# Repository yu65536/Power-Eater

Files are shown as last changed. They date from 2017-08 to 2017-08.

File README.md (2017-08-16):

# Power-Eater
  
This is Ni-MH battery charger for mini4wd.  
 - very low noise and low ripple  
 - dv charge / discharge  
 - cccvdv charge (i thinked new method for mini4wd charger)  
   - race charge method  
   - low internal resigtance, high voltage, many capacity  
   - low life  
 - programable charge/discharge sequence  
   - can use battery tester  
   - complex sequence like IF  

ミニ四駆用ニッケル水素充電器です。  
 - ノイズやリプルが少ない  
 - dv充電や放電ができる  
 - cccvdv充電ができる  
   - レース用途に適している  
   - dv方式に比べて、低内部抵抗、高電圧、大容量の充電が可能  
   - 寿命は短くなる  
 - 充放電シーケンスを組むことができる  
   - 簡易充放電試験機として使用可能  
   - プログラムのIF文のような分岐も可能

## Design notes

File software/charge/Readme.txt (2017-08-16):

-------- PROJECT GENERATOR --------
PROJECT NAME :	charge
PROJECT DIRECTORY :	C:\WorkSpace\charge\charge
CPU SERIES :	R8C/Tiny
CPU GROUP :	25
TOOLCHAIN NAME :	Renesas M16C Standard Toolchain
TOOLCHAIN VERSION :	6.00.00
GENERATION FILES :
    C:\WorkSpace\charge\charge\charge.c
        main program file.
    C:\WorkSpace\charge\charge\nc_define.inc
        interrupt program.
START UP FILES :
    C:\WorkSpace\charge\charge\ncrt0.a30
    C:\WorkSpace\charge\charge\sect30.inc
    C:\WorkSpace\charge\charge\sfr_r825.h
    C:\WorkSpace\charge\charge\sfr_r825.inc

DATE & TIME : 2016/03/07 0:31:16

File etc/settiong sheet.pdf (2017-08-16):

CHG 0 | | CHG 5 | | CHG A | | CHG F
current | A | current | A | current | A | current | A
delta_peak | mV | delta_peak | mV | delta_peak | mV | delta_peak | mV
peak_delay | sec | peak_delay | sec | peak_delay | sec | peak_delay | sec
stop_voltage | V | stop_voltage | V | stop_voltage | V | stop_voltage | V
mode | | mode | | mode | | mode
dec speed | | dec speed | | dec speed | | dec speed
stop current | A | stop current | A | stop current | A | stop current | A
capacity | mAh | capacity | mAh | capacity | mAh | capacity | mAh
CHG 1 | | CHG 6 | | CHG B | | CHG
current | A | current | A | current | A | current | A
delta_peak | mV | delta_peak | mV | delta_peak | mV | delta_peak | mV
peak_delay | sec | peak_delay | sec | peak_delay | sec | peak_delay | sec
stop_voltage | V | stop_voltage | V | stop_voltage | V | stop_voltage | V
mode | | mode | | mode | | mode
dec speed | | dec speed | | dec speed | | dec speed
stop current | A | stop current | A | stop current | A | stop current | A
capacity | mAh | capacity | mAh | capacity | mAh | capacity | mAh
CHG 2 | | CHG 7 | | CHG C | | CHG
current | A | current | A | current | A | current | A
delta_peak | mV | delta_peak | mV | delta_peak | mV | delta_peak | mV
peak_delay | sec | peak_delay | sec | peak_delay | sec | peak_delay | sec
stop_voltage | V | stop_voltage | V | stop_voltage | V | stop_voltage | V
mode | | mode | | mode | | mode
dec speed | | dec speed | | dec speed | | dec speed
stop current | A | stop current | A | stop current | A | stop current | A
capacity | mAh | capacity | mAh | capacity | mAh | capacity | mAh
CHG 3 | | CHG 8 | | CHG D | | CHG
current | A | current | A | current | A | current | A
delta_peak | mV | delta_peak | mV | delta_peak | mV | delta_peak | mV
peak_delay | sec | peak_delay | sec | peak_delay | sec | peak_delay | sec
stop_voltage | V | stop_voltage | V | stop_voltage | V | stop_voltage | V
mode | | mode | | mode | | mode
dec speed | | dec speed | | dec speed | | dec speed
stop current | A | stop current | A | stop current | A | stop current | A
capacity | mAh | capacity | mAh | capacity | mAh | capacity | mAh
CHG 4 | | CHG 9 | | CHG E | | CHG
current | A | current | A | current | A | current | A
delta_peak | mV | delta_peak | mV | delta_peak | mV | delta_peak | mV
peak_delay | sec | peak_delay | sec | peak_delay | sec | peak_delay | sec
stop_voltage | V | stop_voltage | V | stop_voltage | V | stop_voltage | V
mode | | mode | | mode | | mode
dec speed | | dec speed | | dec speed | | dec speed
stop current | A | stop current | A | stop current | A | stop current | A
capacity | mAh | capacity | mAh | capacity | mAh | capacity | mAh

DIS 0 | | DIS 5 | | DIS A | | DIS F
current | A | current | A | current | A | current | A
stop_voltage | V | stop_voltage | V | stop_voltage | V | stop_voltage | V
shibori | | shibori | | shibori | | shibori
dec speed | | dec speed | | dec speed | | dec speed
stop current | A | stop current | A | stop current | A | stop current | A
capacity | mAh | capacity | mAh | capacity | mAh | capacity | mAh
DIS 1 | | DIS 6 | | DIS B | | DIS
current | A | current | A | current | A | current | A
stop_voltage | V | stop_voltage | V | stop_voltage | V | stop_voltage | V
shibori | | shibori | | shibori | | shibori
dec speed | | dec speed | | dec speed | | dec speed
stop current | A | stop current | A | stop current | A | stop current | A
capacity | mAh | capacity | mAh | capacity | mAh | capacity | mAh
DIS 2 | | DIS 7 | | DIS C | | DIS
current | A | current | A | current | A | current | A
stop_voltage | V | stop_voltage | V | stop_voltage | V | stop_voltage | V
shibori | | shibori | | shibori | | shibori
dec speed | | dec speed | | dec speed | | dec speed
stop current | A | stop current | A | stop current | A | stop current | A
capacity | mAh | capacity | mAh | capacity | mAh | capacity | mAh
DIS 3 | | DIS 8 | | DIS D | | DIS
current | A | current | A | current | A | current | A
stop_voltage | V | stop_voltage | V | stop_voltage | V | stop_voltage | V
shibori | | shibori | | shibori | | shibori
dec speed | | dec speed | | dec speed | | dec speed
stop current | A | stop current | A | stop current | A | stop current | A
capacity | mAh | capacity | mAh | capacity | mAh | capacity | mAh
DIS 4 | | DIS 9 | | DIS E | | DIS
current | A | current | A | current | A | current | A
stop_voltage | V | stop_voltage | V | stop_voltage | V | stop_voltage | V
shibori | | shibori | | shibori | | shibori
dec speed | | dec speed | | dec speed | | dec speed
stop current | A | stop current | A | stop current | A | stop current | A
capacity | mAh | capacity | mAh | capacity | mAh | capacity | mAh

SEQ 0 | SEQ 1 0 | 0 1 | 1 2 | 2 3 | 3 4 | 4 5 | 5 6 | 6 7 | 7 8 | 8 9 | 9 A | A B | B C | C D | D E | E F | F
10 | 10
11 | 11
12 | 12
13 | 13
14 | 14
15 | 15
16 | 16
17 | 17
18 | 18
19 | 19
1A | 1A
1B | 1B
1C | 1C
1E | 1E
1F | 1F
20 | 20
21 | 21
22 | 22
23 | 23
24 | 24
25 | 25
26 | 26
27 | 27
28 | 28
29 | 29
2A | 2A
2B | 2B
2C | 2C
2D | 2D
2E | 2E
2F | 2F

SEQ 2 | SEQ 3 0 | 0 1 | 1 2 | 2 3 | 3 4 | 4 5 | 5 6 | 6 7 | 7 8 | 8 9 | 9 A | A B | B C | C D | D E | E F | F
10 | 10
11 | 11
12 | 12
13 | 13
14 | 14
15 | 15
16 | 16
17 | 17
18 | 18
19 | 19
1A | 1A
1B | 1B
1C | 1C
1E | 1E
1F | 1F
20 | 20
21 | 21
22 | 22
23 | 23
24 | 24
25 | 25
26 | 26
27 | 27
28 | 28
29 | 29
2A | 2A
2B | 2B
2C | 2C
2D | 2D
2E | 2E
2F | 2F

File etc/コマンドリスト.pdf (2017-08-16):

## コマンドリスト

1バイト目 | 2バイト目 | 3バイト目 | 4バイト目 | 詳細 | プログラムカウンタ | 備考
0 | 0 | - | - | - cccvΔV charge 0 | | pc = pc + 1
0 | F | - | - | - cccvΔV charge F | | pc = pc + 1
2 | 0 | - | - | - discharge 0 | | pc = pc + 1
2 | F | - | - | - discharge F | | pc = pc + 1
3 | 0 | - | - | - cnt0 = 0 | | pc = pc + 1
3 | 1 | x | - | - cnt0 = x | | pc = pc + 2
3 | 4 | x | - | - cnt0 = cnt0 + x | | pc = pc + 2
3 | 5 | x | - | - cnt0 = cnt0 - x | | pc = pc + 2
3 | 6 | x | y | - if cnt0 == x goto y | | pc = pc + 3
3 | 9 | x | y | - if cnt0 > x goto y | | pc = pc + 3
4 | 0 | - | - | - cnt1 = 0 | | pc = pc + 1
4 | 1 | x | - | - cnt1 = x | | pc = pc + 2
4 | 4 | x | - | - cnt1 = cnt1 + x | | pc = pc + 2
4 | 5 | x | - | - cnt1 = cnt1 - x | | pc = pc + 2
4 | 6 | x | y | - if cnt1 == x goto y | | pc = pc + 3
4 | 9 | x | y | - if cnt1 > x goto y | | pc = pc + 3
5 | 0 | - | - | - cnt2 = 0 | | pc = pc + 1
5 | 1 | x | - | - cnt2 = x | | pc = pc + 2
5 | 4 | x | - | - cnt2 = cnt2 + x | | pc = pc + 2
5 | 5 | x | - | - cnt2 = cnt2 - x | | pc = pc + 2
5 | 6 | x | y | - if cnt2 == x goto y | | pc = pc + 3
5 | 9 | x | y | - if cnt2 > x goto y | | pc = pc + 3
6 | 0 | - | - | - cnt3 = 0 | | pc = pc + 1
6 | 1 | x | - | - cnt3 = x | | pc = pc + 2
6 | 4 | x | - | - cnt3 = cnt3 + x | | pc = pc + 2
6 | 5 | x | - | - cnt3 = cnt3 - x | | pc = pc + 2
6 | 6 | x | y | - if cnt3 == x goto y | | pc = pc + 3
6 | 9 | x | y | - if cnt3 > x goto y | | pc = pc + 3
7 | 0 | x | y | - if (end_flag) and x != 0 goto y | | pc = pc + 3 | 終了条件で分岐　※
8 | 0 | x | y | z if end_voltage == (x*256+y)/1000 then goto z | | pc = pc + 4 | 終了時の電圧で分岐
8 | 3 | x | y | z if end_voltage > (x*256+y)/1000 then goto z | | pc = pc + 4 | 終了時の電圧で分岐
8 | 6 | x | y | z if end_current == (x*256+y)/100 then goto z | | pc = pc + 4 | 終了時の電流で分岐
8 | 9 | x | y | z if end_current > (x*256+y)/100 then goto z | | pc = pc + 4 | 終了時の電流で分岐
8 | C | x | y | z if end_capacity == x*256+y then goto z | | pc = pc + 4 | 終了時の容量で分岐
8 | F | x | y | z if end_capacity > x*256+y then goto z | | pc = pc + 4 | 終了時の容量で分岐
A | 0 | x | - | - wait x sec | | pc = pc + 2
A | 1 | x | - | - wait x min | | pc = pc + 2
A | 2 | - | - | - | 容量累積モード ON | pc = pc + 1 | 初期値が不明のため、 累積モードON時は 必ず容量リセットを実行する。
A | 3 | - | - | - | 容量累積モード OFF | pc = pc + 1
A | 4 | - | - | - 容量累積モード 容量リセット | | pc = pc + 1
B | 0 | x | - | - goto x | | pc = pc + 2
C | 0 | - | - | - end | | exit
F | F | - | - | - end | | exit

※ end_flag

各充放電モードの終了に終了の原因となった条件のフラグが立ち、フラグによってシーケンスが分岐する。

各モードのフラグは下記の通り。

CCCVΔV charge | discharge

8bitのフラグを16進数に変換して入力する。
11000010なら入力する値はC2となる。

上記の場合、0, 1, 6bit目のどれかのフラグが立てば分岐する。

0：cancel | 0：cancel
1：delta voltage | 1：voltage
2：voltage | 2：current
3：current | 3：capacity
4：capacity | 4：
5： | 5：
6： | 6：
7： | 7：

# コマンドリスト

フラグ | end_flag

## CCCVΔV charge 0 cancel 1 dlta peak 2 volt 3 current 4 capacity

5
6
7

## discharge 0 cancel 1 volt 2 current 3 capacity

4
5
6
7

### 0が最上位ビット 16進数に直して入力する 11000010なら入力する値はC2となる 0, 1, 6のどれかが成立すれば分岐する

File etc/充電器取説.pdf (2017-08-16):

## 充電器 取扱説明書

【注意】
本充電器は趣味で作成した個人製作の充電器であるため、十分な数量、時間の評価を行え ていません。
使用の際には、火災や感電に十分にご注意ください。
問題が発生した際も当方は一切の責任を負わないことをご了承ください。
ミニ四駆 フラットレース向けに設計しているため、それ以外の用途では十分な性能を発揮で きない可能性があります。

【概要】
入力：DC7.4V（※1） / 5A（充電電流＋1A）
出力：ニッケル水素電池 2 セル / 4A（※2）
※1：一般的な充電器で使用している DC12V 電源では破損の恐れがあります。 DC/DC コンバータ等を使用して DC7.4V で使用してください。 ※2：設定は 7A まで可能。
フラットレースでの追い充電時の緊急用に設定できるようにしています。 7A での充放電は動作確認をしていません。
充電機能：ΔV 充電、CCCVΔV 充電、ピークディレイ、電圧カット、容量カット 放電機能：CC 放電、絞り放電、電圧カット、容量カット その他：シーケンスモード、PC モニタ機能

【特徴】
本充電器の特徴として以下の三点が挙げられる。
- 高精度な電流制御
ニッケル水素電池の充電では mV 単位で正確に電圧を検出する必要があるため、高 精度な電流制御が必要とされる。
一般的な充電器では電流制御にパルス幅変調方式（以下 PWM 方式）が使用されてい る。PWM 方式では制御素子の ON/OFF に合わせてリプル電流と呼ばれる脈流が発生し、 精度悪化の要因となっている。
本充電器ではパルス振幅変調方式（以下 PAM 方式）を採用することでリプル電流を抑 制し、より高精度な充電を行えるようにした。
- CCCVΔV 充電
充電時の電池温度を抑えることは電池寿命の増大や内部抵抗管理の簡便性に繋が るため、充電器の重要な性能の一つである。
一般的な充電器で使用される ΔV 方式の充電器では発熱による内部抵抗の変化を検 出するため、原理上、充電終了時の電池温度を発熱を抑えることは困難である。 本充電器ではニッケル水素電池向けに新たな充電方式を開発した。CCCV 方式をベー スに ΔV の検出も行うため、安全かつ低温で充電を行うことができる。

- シーケンスモード
各人の用途、趣向に合致した充電を行うためには、より多様な充電設定を行える必要 がある。
本充電器では複数の充電設定、放電設定を組み合わせたシーケンスを設定可能な モードを備える。このシーケンスモードを利用することでサイクル充電や多段階の充放電 も行うことが可能である。
また、分岐命令やカウンタも用意されており、従来の充電器では不可能である複雑な 充放電設定を行うことができる。

【接続】
下図を参考に電池ボックス、電源を接続してください。

【基本操作】
上ボタン：項目/値を変更
下ボタン：項目/値を変更
右ボタン：決定/充電時の電流変更
左ボタン：キャンセル

充電器

+ IN
- IN

+ OUT
+ OUT-S
- OUT
- OUT-S

電源

電池ボックス

※

※ 電池ボックス＋から二本、－から二本接続する。

+

+

【PC モニタ機能】
シリアルケーブル（ストレート）で PC と接続することで充放電状況を PC からモニタすることがで きます。
下記の設定は参考にターミナルソフトを設定してください。

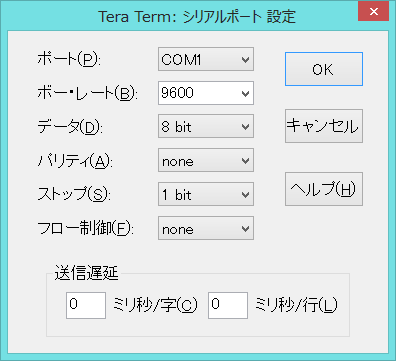
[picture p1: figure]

【フラットレースにおける充電】
フラットレースでは基礎充電、追い充電と呼ばれる充電を行います。基礎充電は電池を満充 電にするために行い、追い充電はレース直前に内部抵抗を低下させ電池出力を上げるために行 います。
追い充電での精度を上げるために、基礎充電では電池温度を上昇させずに満充電まで充電 することが重要です。
電池温度が高い状態では電池内部で自己放電と呼ばれる現象が発生し、電池の残容量は減 少していきます。どの程度放電したかはわからないため、後の追い充電にも誤差が発生します。 一般的に使用される ΔV 方式の充電器では発熱による電圧の変化を検出するため、電池温 度の低い状態では正確な ΔV の検出ができません。また ΔV はあくまでも満充電付近での発熱 を検出するだけであり、正確な満充電に至るには更に充電を行う必要があります。もちろん電池 は更に発熱します。

【CCCVΔV 充電】
前項で示した充電を行うために CCCV 充電を行う必要があります。
CCCV 充電では電池電圧が設定電圧に到達すると充電電流を低下させ、設定電圧を保持しな がら充電を行います。つまり満充電が近づくにつれ電流が低下するため、電池の発熱を最低限 に抑えることが可能です。
しかし設定電圧を ΔV 発生時の電池電圧以上に設定してしまった場合、初期電流のまま充電 を継続することとなり電池は過充電に陥ってしまいます。
本充電器では CCCV 充電と ΔV 検出を組み合わせた CCCVΔV 充電が可能です。CCCVΔV 充電 では設定電圧を誤った場合でも ΔV を検出し安全に充電を停止します。

【充電手順】
1. 充電を開始するには『CCCVΔV CHARGE』を選択してください。
2. 充電設定を選択してください。16 個の充電設定を保存出来ます。
3. 充電設定を変更します。
- CURRENT：充電電流を設定します。
- DELTA PEAK：ΔV を設定します。2 セル分の値を設定します。 （ex.6mV 設定：1 セルあたり 3mV）
- PEAK DELAY：設定した期間 ΔV の検出を行いません。
- STOP VOLT：CCCVΔV モードでは電池電圧を設定します。
CC+OVP モードでは過電圧保護閾値を設定します。
2 セル分の値を設定します。
- | CVMODE：『CV->TRICKLE』 | CCCVΔV 方式で充電後、トリクル充電を行います。
| 『CV->STOP』 | CCCVΔV 方式で充電後、停止します
| 『CC+OVP』 | ΔV 方式でします。
- STOP CUR：CCCVΔV 充電を終了する電流を設定します。『CVMODE』で『CV->TRICKLE』 を選択した場合、充電終了後に『STOP CUR』設定値でトリクル充電を行います。
- DEC SPEED：電流の減少速度を調整します。CCCVΔV で電流の減少が間に合わなけ れば増やしてください。
- STOP CAP：充電を終了する容量を設定します。
- SAVE：設定データを保存します。
4. 『START』を選択し充電を開始します。

【充電画面】
充電画面の詳細は下図の通りです。

充電中は右ボタンで電流の変更を行うことができます。
充電中は左ボタンで充電を中止することができます。

3.1234V 0123mAh
0.00A 0.00A
電池電圧 | 充電容量
設定電流 | 電流モニタ

【放電手順】
1. 放電を開始するには『DISCHARGE』を選択してください。
2. 放電設定を選択してください。16 個の放電設定を保存出来ます。
3. 放電設定を変更します。
- CURRENT：放電電流を設定します。
- STOP VOLT：終了電圧を設定します。2 セル分の値を設定します。
- SHIBORI：絞り放電の有無を設定します。
電池電圧が『STOP VOLT』に到達すると電流を減少させ放電を継続します。
- DEC SPEED：電流の減少速度を調整します。絞り放電で電流の減少が間に合わなけれ ば増やしてください。
- STOP CUR：絞り放電使用時に放電を終了する電流を設定します。
- STOP CAP：放電を終了する容量を設定します。
- SAVE：設定データを保存します。
4. 『START』を選択し放電を開始します。

放電中は左ボタンで放電を中止することができます。

【放電画面】
放電画面の詳細は下図の通りです。

放電中は左ボタンで放電を中止することができます。

3.1234V 0123mAh
0.00A 0.00A
電池電圧 | 放電容量
設定電流 | 電流モニタ

【シーケンス実行手順】
1. シーケンスを開始するには『SEQUENCE』を選択してください。
2. シーケンスを選択してください。4 個のシーケンスを保存出来ます。
3. シーケンスを変更します。
- 0～FF 行までの各行に添付のコマンドリストに従ってコマンドを入力します。
4. 『START』を選択しシーケンスを開始します。

【コマンドリストの見方】
- ①に記載された数字（16 進数）がコマンドになります。
- コマンド以外に値を必要とする場合があり②が『-』以外の場合は次の行に値を入力しま す。
- シーケンスモードでは内部変数 PC に示す行のコマンドを実行します。（PC 初期値は 0）
- コマンドの実行内容は③に記載されています。
- コマンド実行後は④で指示された値に PC を書き換え次のコマンドを実行します。 ただし②で『goto x』と記載されている場合は x で指定された値を PC に書き込みます。
1 バイト目 | 2 バイト目 | … | 詳細 | プログラムカウンタ
20 | - | | discharge 0 | PC = PC + 1
31 | x | | cnt0 = x | PC = PC + 2

【シーケンス例１】
内容：サイクル充電を 3 回行う
行番号 | 設定値 | 備考
0 | 0 | 充電設定 0 を実行
1 | 20 | 放電設定 0 を実行
2 | 0 | 充電設定 0 を実行
3 | 20 | 放電設定 0 を実行
4 | 0 | 充電設定 0 を実行
5 | 20 | 放電設定 0 を実行
6 | C0 | シーケンスを終了

SEQ0-00 SETTING
00
設定番号 | 行番号

設定値

① | ② | ③ | ④

【シーケンス例 2】
内容：サイクル充電を 100 回行う
行番号 | 設定値 | 備考
0 | 31 | cnt0 に 100 を代入
1 | 64 | 100 (16 進数)
2 | 1 | 充電設定 1 を実行
3 | A0 | 10 秒待機
4 | A | 値：10
5 | 21 | 放電設定 1 を実行
6 | 35 | cnt0 から 1 を引く
7 | 1 | 値：1
8 | A1 | 1 分待機
9 | 1 | 値：1
A | 36 | cnt0 が 0 なら F 行目に移動
B | 0 | 値：0
C | F | F 行目
D | B0 | 2 行目に移動
E | 2 | 2 行目
F | C0 | シーケンスを終了

【シーケンス例 3】
内容：2 段階充電
行番号 | 設定値 | 備考
0 | A2 | 容量累積表示モード　ON
1 | A4 | 容量を初期化
2 | 0 | 充電設定 0 を実行
3 | 70 | キャンセルされたら 7 行目に移動
4 | 80 | キャンセルフラグ
5 | 7 | 7 行目
6 | 1 | 充電設定 1 を実行
7 | A3 | 容量累積表示モード　OFF
8 | C0 | シーケンスを終了

【シーケンス例 4】
内容：電池電圧が 3.2V になるまで充放電を繰り返す（電池起こし）
行番号 | 設定値 | 備考
0 | 0 | 充電設定 0 を実行
1 | 20 | 放電設定 0 を実行（0.1A, 1mAh） （電池電圧の確認）
2 | 83 | 電池電圧が 3.2V より大きい場合 xx 行 目に移動
3 | 0B | 値：3.000V
4 | B8
5 | 9 | 9 行目
6 | 21 | 放電設定 1 を実行
7 | B0 | 0 行目に移動
8 | 0 | 0 行目
9 | 21 | 放電設定 1 を実行
A | C0 | シーケンスを終了

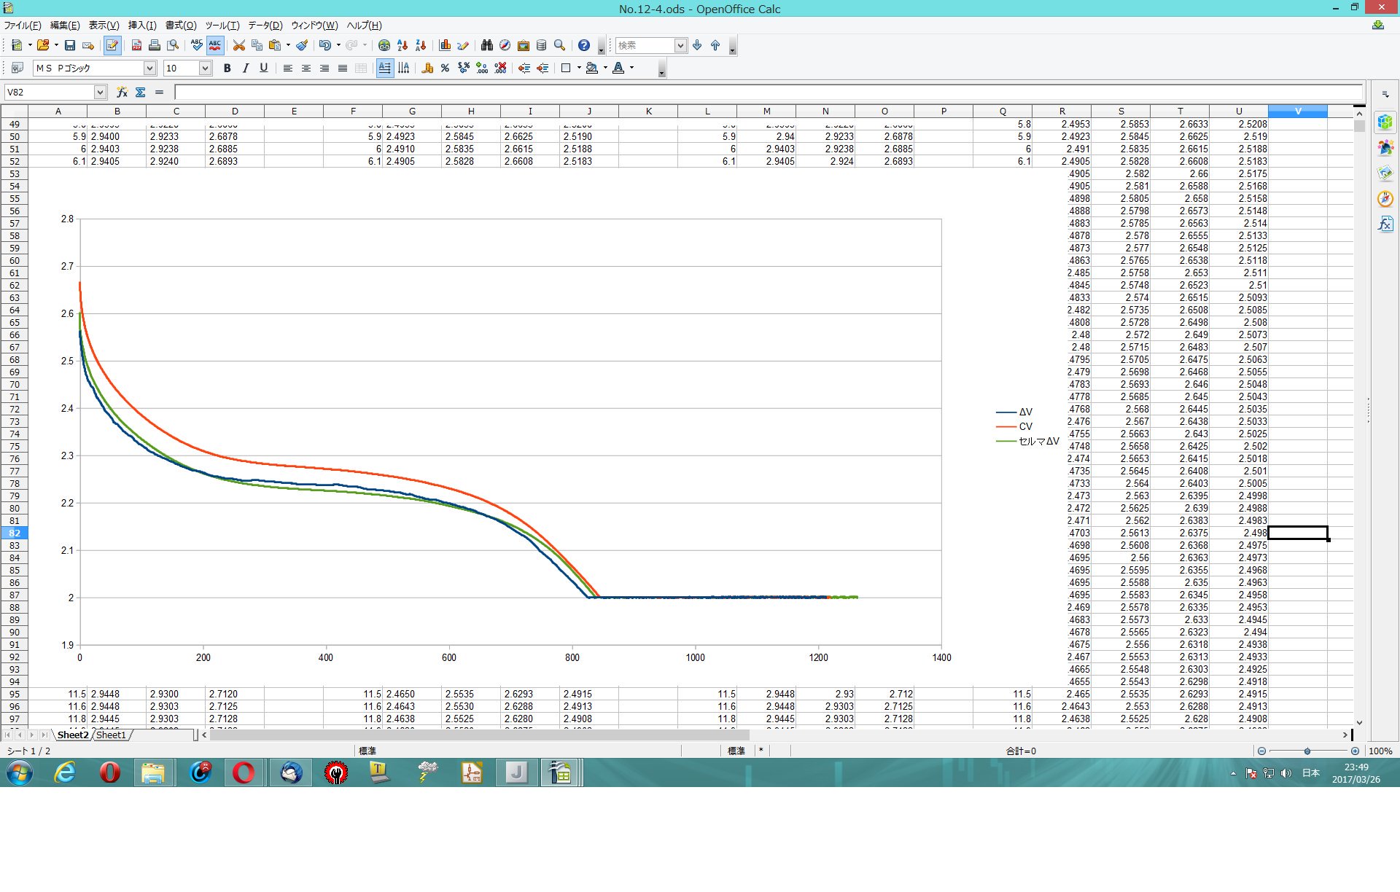
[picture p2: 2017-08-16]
etc/dv-vs-cccv.jpg

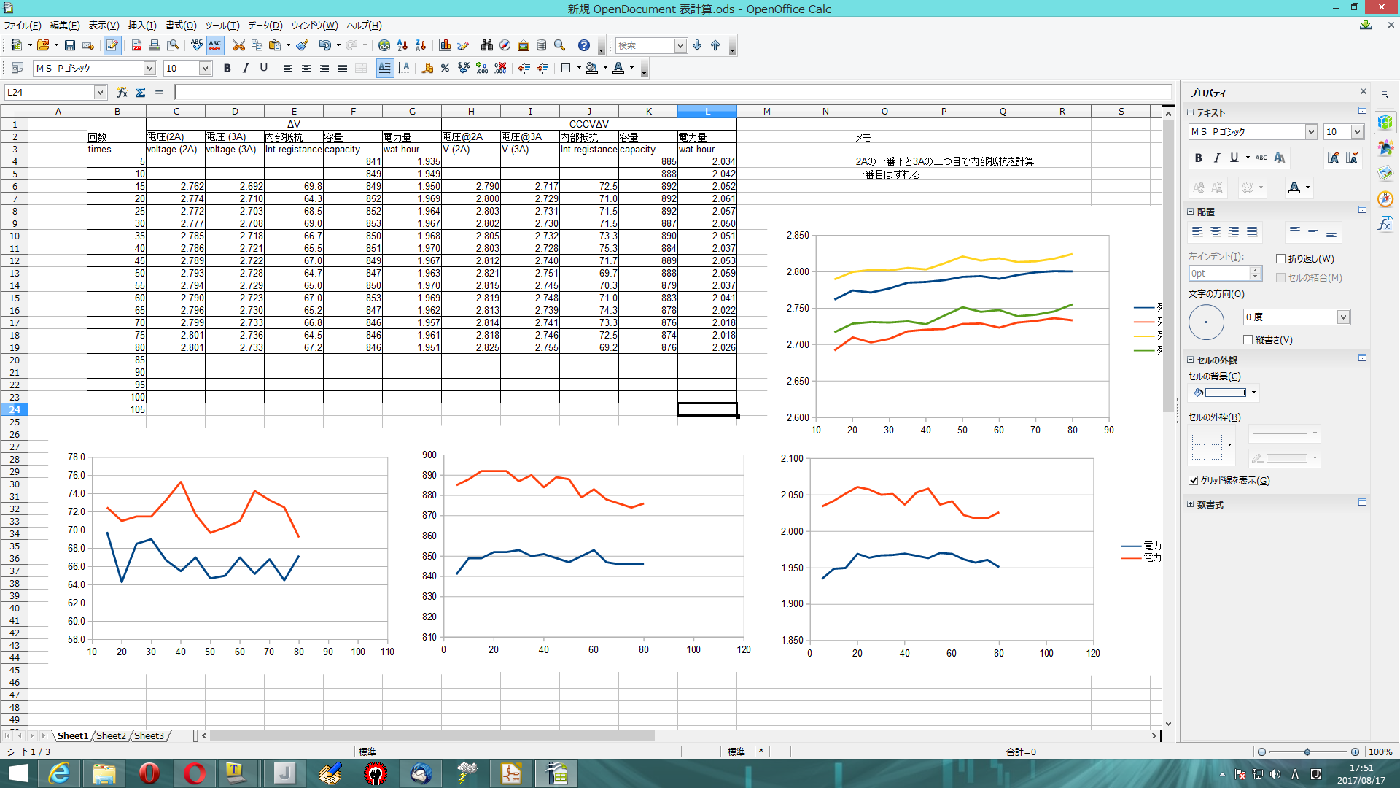
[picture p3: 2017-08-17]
etc/bat life.png

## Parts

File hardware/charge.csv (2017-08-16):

Reference | Value | Footprint | Datasheet
R13 | 0 | Resistors_SMD:R_0603
R17 | 0 | Resistors_SMD:R_0603
R3 | 1 | Resistors_SMD:R_2512
R38 | 1 | Resistors_SMD:R_2512
R39 | 1 | Resistors_SMD:R_2512
R40 | 1 | Resistors_SMD:R_2512
R41 | 1 | Resistors_SMD:R_2512
R42 | 1 | Resistors_SMD:R_2512
R43 | 1 | Resistors_SMD:R_2512
R44 | 1 | Resistors_SMD:R_2512
R45 | 1 | Resistors_SMD:R_2512
R46 | 1 | Resistors_SMD:R_2512
R47 | 1 | Resistors_SMD:R_2512
R48 | 1 | Resistors_SMD:R_2512
R49 | 1 | Resistors_SMD:R_2512
R50 | 1 | Resistors_SMD:R_2512
R51 | 1 | Resistors_SMD:R_2512
R7 | 1 | Resistors_SMD:R_2512
R14 | 100 | Resistors_SMD:R_0603
R16 | 100 | Resistors_SMD:R_0603
R20 | 100 | Resistors_SMD:R_0603
R21 | 100 | Resistors_SMD:R_0603
R27 | 100 | Resistors_SMD:R_0603
R28 | 100 | Resistors_SMD:R_0603
R29 | 100 | Resistors_SMD:R_0603
R30 | 100 | Resistors_SMD:R_0603
R15 | 470 | Resistors_SMD:R_0603
R35 | 470 | Resistors_SMD:R_0603
C36 | 0.01u | Capacitors_SMD:C_0603
C37 | 0.01u | Capacitors_SMD:C_0603
C10 | 0.1u | Capacitors_SMD:C_0603
C11 | 0.1u | Capacitors_SMD:C_0603
C12 | 0.1u | Capacitors_SMD:C_0603
C13 | 0.1u | Capacitors_SMD:C_0603
C14 | 0.1u | Capacitors_SMD:C_0603
C15 | 0.1u | Capacitors_SMD:C_0603
C17 | 0.1u | Capacitors_SMD:C_0603
C18 | 0.1u | Capacitors_SMD:C_0603
C2 | 0.1u | Capacitors_SMD:C_0603
C20 | 0.1u | Capacitors_SMD:C_0603
C23 | 0.1u | Capacitors_SMD:C_0603
C24 | 0.1u | Capacitors_SMD:C_0603
C31 | 0.1u | Capacitors_SMD:C_0603
C32 | 0.1u | Capacitors_SMD:C_0603
C33 | 0.1u | Capacitors_SMD:C_0603
C34 | 0.1u | Capacitors_SMD:C_0603
C35 | 0.1u | Capacitors_SMD:C_0603
C4 | 0.1u | Capacitors_SMD:C_0603
C5 | 0.1u | Capacitors_SMD:C_0603
C7 | 0.1u | Capacitors_SMD:C_0603
C8 | 0.1u | Capacitors_SMD:C_0603
C9 | 0.1u | Capacitors_SMD:C_0603
R11 | 10k | Resistors_SMD:R_0603
R12 | 10k | Resistors_SMD:R_0603
R19 | 10k | Resistors_SMD:R_0603
R23 | 10k | Resistors_SMD:R_0603
R24 | 10k | Resistors_SMD:R_0603
R25 | 10k | Resistors_SMD:R_0603
R26 | 10k | Resistors_SMD:R_0603
R31 | 10k | Resistors_SMD:R_0603
R32 | 10k | Resistors_SMD:R_0603
R36 | 10k | Resistors_SMD:R_0603
R37 | 10k | Resistors_SMD:R_0603
C28 | 18p | Capacitors_SMD:C_0603
C29 | 18p | Capacitors_SMD:C_0603
R10 | 1k | Resistors_SMD:R_0603
R4 | 1k | Resistors_SMD:R_0603
C19 | 1u | Capacitors_SMD:C_0805
C21 | 1u | Capacitors_SMD:C_0805
C22 | 1u | Capacitors_SMD:C_0805
C25 | 1u | Capacitors_SMD:C_0805
C30 | 1u | Capacitors_SMD:C_0805
R18 | 20k | Resistors_SMD:R_0603
R22 | 20k | Resistors_SMD:R_0603
R5 | 20k | Resistors_SMD:R_0603
R6 | 20k | Resistors_SMD:R_0603
R8 | 20k | Resistors_SMD:R_0603
R9 | 20k | Resistors_SMD:R_0603
C26 | 22p | Capacitors_SMD:C_0603
C27 | 22p | Capacitors_SMD:C_0603
Q1 | 2SD2390 | TO_SOT_Packages_THT:TO-247_PadsOnly_Neutral123
Q2 | 2SD2390 | TO_SOT_Packages_THT:TO-247_PadsOnly_Neutral123
R33 | 4.7k | Resistors_SMD:R_0603
R34 | 4.7k | Resistors_SMD:R_0603
C1 | 470u | Capacitors_ThroughHole:C_Radial_D8_L11.5_P3.5
C16 | 47u | Capacitors_ThroughHole:C_Rect_L7_W4.5_P5
C3 | 47u | Capacitors_ThroughHole:C_Rect_L7_W4.5_P5
C38 | 47u | Capacitors_ThroughHole:C_Rect_L7_W4.5_P5
C6 | 47u | Capacitors_ThroughHole:C_Radial_D5_L11_P2.5
U10 | ADM3202ARN | IC:ADM3202ARN
DS1 | AQM1602A | charge:AQM1602A
P1 | BH-6-15 | charge:BH-6-15
P10 | BH-6-15 | charge:pad-3-3
P2 | BH-6-15 | charge:BH-6-15
P3 | BH-6-15 | charge:BH-6-15
P4 | BH-6-15 | charge:BH-6-15
P5 | BH-6-15 | charge:BH-6-15
P6 | BH-6-15 | charge:BH-6-15
P7 | BH-6-15 | charge:pad-3-3
P8 | BH-6-15 | charge:pad-3-3
P9 | CONN_01X09 | Connect:DB9MD
X2 | FA-238 20MHz | Crystals:crystal_FA238-TSX3225
X1 | FC-255 32.768kHz | charge:FC-255
JP1 | JUMPER | Pin_Headers:Pin_Header_Straight_1x02
JP2 | JUMPER | Pin_Headers:Pin_Header_Straight_1x02
D10 | LED | LEDs:LED_0603
D3 | LED | LEDs:LED_0603
U2 | LM2940 | REG:LM2940CT-5.0
U8 | M51957BFP | IC:M51957B
U6 | MCP3425A0T-E/CH | TO_SOT_Packages_SMD:SOT-23-6
U7 | MCP4922-E/P | IC:MCP4922-E_P
U1 | NJM2119 | IC:NJM2119D
U3 | NJM2119 | IC:NJM2119D
U4 | NJM2119 | IC:NJM2119D
U5 | NJM2825 | TO_SOT_Packages_SMD:SOT-23-5
U9 | R5F21256SNFP | MCU_Renesas:R5F21256SNFP
D2 | RB751S-40 | Diodes_SMD:SOD-523
D4 | RB751S-40 | Diodes_SMD:SOD-523
D5 | RB751S-40 | Diodes_SMD:SOD-523
D6 | RB751S-40 | Diodes_SMD:SOD-523
D7 | RB751S-40 | Diodes_SMD:SOD-523
D8 | RB751S-40 | Diodes_SMD:SOD-523
D9 | RB751S-40 | Diodes_SMD:SOD-523
D1 | SBM1045VSS | D:SBM1045VSS
SW1 | SW_PUSH | Buttons_Switches_ThroughHole:SW_PUSH_6mm
SW2 | SW_PUSH | Buttons_Switches_ThroughHole:SW_PUSH_6mm
SW3 | SW_PUSH | Buttons_Switches_ThroughHole:SW_PUSH_6mm
SW4 | SW_PUSH | Buttons_Switches_ThroughHole:SW_PUSH_6mm

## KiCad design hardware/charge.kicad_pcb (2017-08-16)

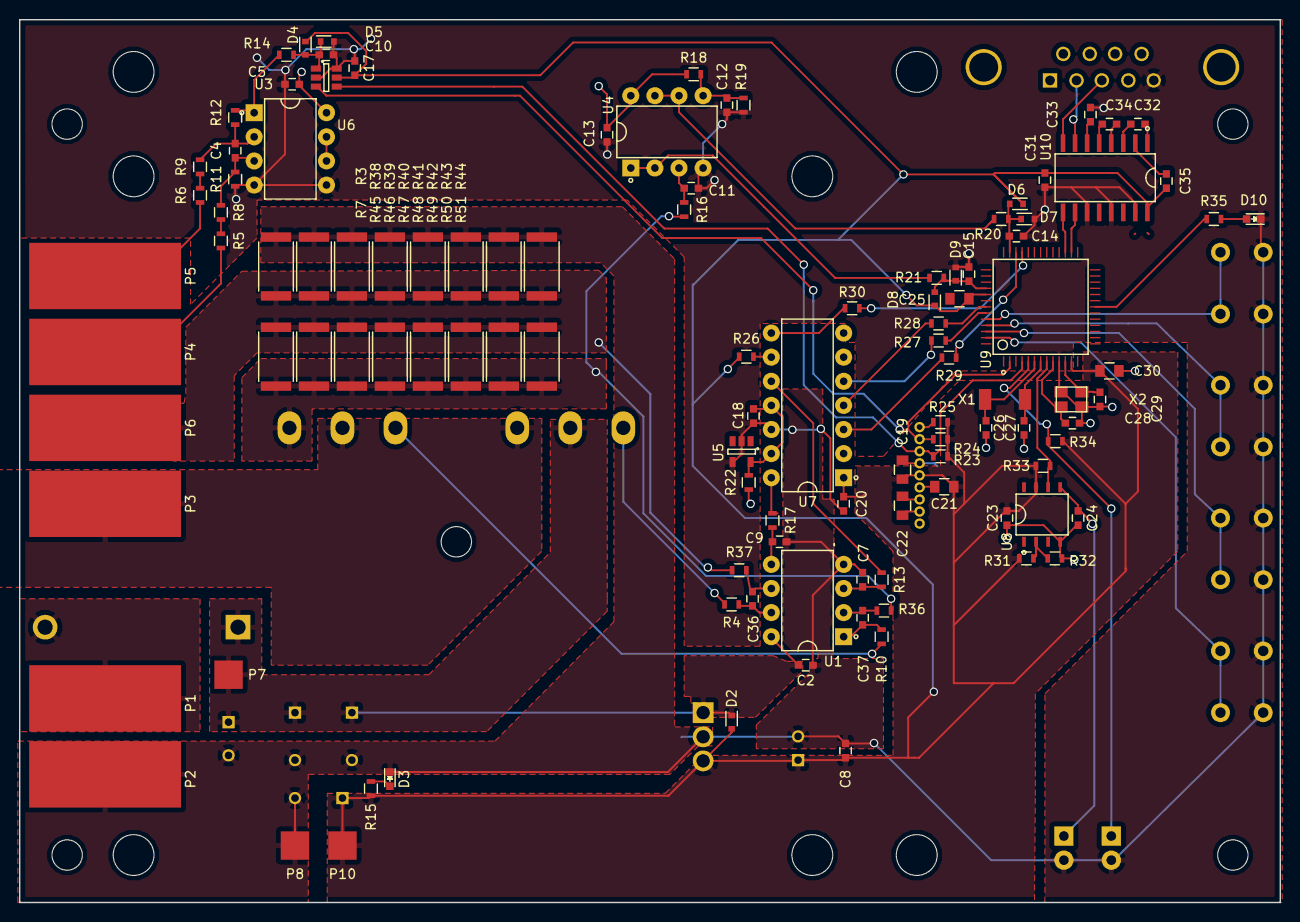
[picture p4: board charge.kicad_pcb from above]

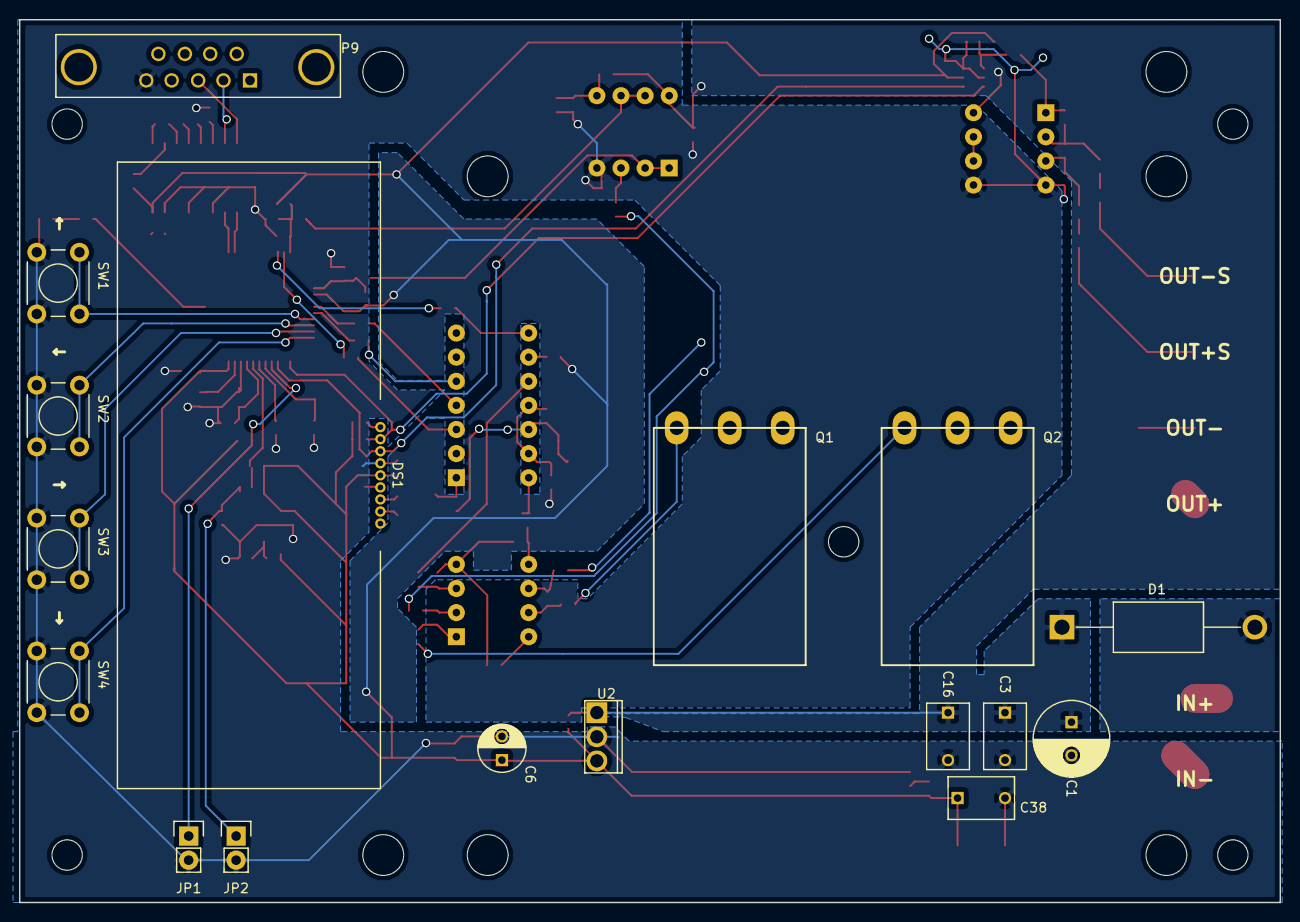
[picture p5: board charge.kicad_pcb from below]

Board: 2 copper layers, 132.8 x 93.0 mm, 128 parts (17 on the bottom side), 73 nets.

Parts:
C1: 470u; C_Radial_D8_L11.5_P3.5
C2, C4, C5, C7, C8, C9, C10, C11, C12, C13, C14, C15, C17, C18, C20, C23, C24, C31, C32, C33, C34, C35: 0.1u; C_0603
C3, C16, C38: 47u; C_Rect_L7_W4.5_P5
C6: 47u; C_Radial_D5_L11_P2.5
C19, C21, C22, C25, C30: 1u; C_0805
C26, C27: 22p; C_0603
C28, C29: 18p; C_0603
C36, C37: 0.01u; C_0603
D1: SBM1045VSS
D2, D4, D5, D6, D7, D8, D9: RB751S-40; SOD-523
D3, D10: LED; LED_0603
DS1: AQM1602A
JP1, JP2: JUMPER; Pin_Header_Straight_1x02
P1, P2, P3, P4, P5, P6: BH-6-15
P7, P8, P10: BH-6-15; pad-3-3
P9: CONN_01X09; DB9MD
Q1, Q2: 2SD2390; TO-247_PadsOnly_Neutral123
R3, R7, R38, R39, R40, R41, R42, R43, R44, R45, R46, R47, R48, R49, R50, R51: 1; R_2512
R4, R10: 1k; R_0603
R5, R6, R8, R9, R18, R22: 20k; R_0603
R11, R12, R19, R23, R24, R25, R26, R31, R32, R36, R37: 10k; R_0603
R13, R17: 0; R_0603
R14, R16, R20, R21, R27, R28, R29, R30: 100; R_0603
R15, R35: 470; R_0603
R33, R34: 4.7k; R_0603
SW1, SW2, SW3, SW4: SW_PUSH; SW_PUSH_6mm
U1, U3, U4: NJM2119; NJM2119D
U2: LM2940; LM2940CT-5.0
U5: NJM2825; SOT-23-5
U6: MCP3425A0T-E/CH; SOT-23-6
U7: MCP4922-E/P; MCP4922-E_P
U8: M51957BFP; M51957B
U9: R5F21256SNFP
U10: ADM3202ARN
X1: FC-255 32.768kHz; FC-255
X2: FA-238 20MHz; crystal_FA238-TSX3225

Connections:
+5V: C6.1, C8.1, C17.1, C19.2, C20.1, C21.2, C23.1, C25.1, C30.1, C31.1, C35.1, C38.1, D2.2, D4.1, D6.1, D8.1, DS1.5, P10.1, R15.2, R22.1, R23.1, R24.1, R25.1, R26.1, R31.1, R33.1, R34.1, U2.3, U6.5, U7.1, U8.7, U9.12, U9.44, U10.16
AD: C10.1, D4.2, D5.1, R14.1, U6.1
CS: R29.1, U9.37
DA1: R17.1, U7.14
DA2: R13.1, U7.10
GND: C1.2, C2.2, C3.2, C5.2, C6.2, C7.2, C8.2, C9.2, C10.2, C11.2, C12.2, C13.2, C14.2, C15.2, C16.2, C17.2, C18.2, C19.1, C20.2, C23.2, C24.2, C25.2, C26.2, C27.1, C28.2, C29.1, C30.2, C31.2, C33.2, C38.2, D3.1, D5.2, D7.2, D9.2, D10.1, DS1.4, JP1.2, JP2.2, P2.1, P8.1, P9.5, R3.2, R11.1, R19.1, R32.2, R38.2, R39.2, R40.2, R41.2, R42.2, R43.2, R44.2, SW1.1, SW2.1, SW3.1, SW4.1, U1.4, U2.2, U3.4, U3.5, U4.4, U5.2, U5.4, U6.2, U6.6, U7.12, U8.4, U9.10, U10.11, U10.13, U10.15, X2.3
I2C_SCL: DS1.2, R24.2, U6.3, U9.2
I2C_SDA: DS1.3, R23.2, U6.4, U9.4
LDAC: R30.1, U9.36
unnamed: C4.1, R8.1, R11.2, U3.3
unnamed: C4.2, R9.1, R12.2, U3.2
unnamed: C7.1, R13.2, U1.3
unnamed: C9.1, R17.2, U1.5
unnamed: C11.1, R16.1, U4.3
unnamed: C12.1, R18.1, R19.2, U4.5
unnamed: C18.1, R22.2, U5.5, U7.11, U7.13
unnamed: C21.1, DS1.6
unnamed: C22.1, DS1.8
unnamed: C22.2, DS1.7
unnamed: C24.1, JP2.1, U8.5
unnamed: C26.1, U9.6, X1.1
unnamed: C27.2, U9.7, X1.2
unnamed: C28.1, U9.9, X2.1
unnamed: C29.2, U9.11, X2.2
unnamed: C32.1, U10.1
unnamed: C32.2, U10.3
unnamed: C33.1, U10.6
unnamed: C34.1, U10.4
unnamed: C34.2, U10.5
unnamed: C35.2, U10.2
unnamed: C36.1, R37.2, U1.6
unnamed: C36.2, R4.1, U1.7
unnamed: C37.1, R36.1, U1.2
unnamed: C37.2, R10.1, U1.1
unnamed: D1.2, P1.1
unnamed: D3.2, R15.1
unnamed: D10.2, R35.2
unnamed: DS1.1, R25.2
unnamed: JP1.1, R34.2, U9.5
unnamed: P3.1, Q1.3, Q2.2
unnamed: P4.1, R5.2
unnamed: P5.1, R6.2
unnamed: P6.1, R3.1, R7.2, R37.1, R38.1, R39.1, R40.1, R41.1, R42.1, R43.1, R44.1, R45.2, R46.2, R47.2, R48.2, R49.2, R50.2, R51.2
unnamed: P9.2, U10.7
unnamed: P9.3, U10.8
unnamed: Q1.1, R4.2
unnamed: Q2.1, R10.2
unnamed: Q2.3, R7.1, R16.2, R36.2, R45.1, R46.1, R47.1, R48.1, R49.1, R50.1, R51.1
unnamed: R5.1, R8.2
unnamed: R6.1, R9.2
unnamed: R12.1, R14.2, U3.1
unnamed: R20.2, U4.6, U4.7
unnamed: R21.2, U4.1, U4.2
unnamed: R26.2, U7.9
unnamed: R27.2, U7.5
unnamed: R28.2, U7.4
unnamed: R29.2, U7.3
unnamed: R30.2, U7.8
unnamed: R31.2, R32.1, U8.2
unnamed: R33.2, U8.6, U9.8
unnamed: R35.1, U9.20
unnamed: SW1.2, U9.48
unnamed: SW2.2, U9.49
unnamed: SW3.2, U9.50
unnamed: SW4.2, U9.51
unnamed: U3.6, U3.7
unnamed: U9.29, U10.9
unnamed: U9.28, U10.10
SCK: R28.1, U9.46
SDI: R27.1, U9.47
VCC: C1.1, C2.1, C3.1, C5.1, C13.1, C16.1, D1.1, D2.1, P7.1, Q1.2, R18.2, U1.8, U2.1, U3.8, U4.8
bat_moni: C14.1, D6.2, D7.1, R20.1, U9.38
i_moni: C15.1, D8.2, D9.1, R21.1, U9.43

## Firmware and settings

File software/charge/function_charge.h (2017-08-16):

void init(void);
void display_menu(int status);
char check_sw(void);
void read_data(unsigned char *write_adr, unsigned int read_adr, int size);
void write_data(unsigned int bank, unsigned int write_index, unsigned char *data_pointer, unsigned int size);
void display_setting(char num, char point, unsigned char hi, unsigned char lo, char *unit);
void change_setting(char num, char point, unsigned char *hi, unsigned char *lo, int max, int min, char *unit);


void status_change(void);
void setting_change(void);

void edit_mode_on(void);
void edit_mode_off(void);

void data_check(char *data);

void charge(void);
void cvcharge(void);
void discharge(void);
void sequence(void);


char convert_4to10[4] = {0,3,5,8};

void current_to_current_char(void);
void current_char_to_current(void);

int ad_read_internal(int ch);
void bat_test(void);
void data_erase(void);



unsigned char data[1024];
unsigned char data_seq[256];
unsigned char data_setting[16];
unsigned char setting_mode;
unsigned char setting_place;

char seq_mode;

char current_char[3];
unsigned int current;
unsigned int stop_current;
unsigned int current_monitor;
unsigned int voltage;
unsigned int voltage_monitor;
unsigned int voltage_max;

unsigned char shibori;

unsigned long capacity;
unsigned long capacity_monitor;
unsigned int delta_peak;
unsigned int peak_delay;
unsigned char mode;
unsigned char mode_shibori;

unsigned char cv_trickle_mode;
unsigned char dec_speed;

unsigned long time_cnt;


unsigned char pc;

unsigned char end_flag;
unsigned char seq_cnt[4];

char cap_mode;
char buf[16];



void init(void)
{
	clk_setting();
	serial1_setting();
	timer_setting();
	sw_setting();
	lcd_setting();
	ad_setting();
	da_setting();
	p2 = 0b00000000;
//	p2drr = 0b10000000;
//	trdoer1 = 0b11111111;
//	pd2 = 0b11100000;	
	pd2 = 0b00000001;
	p2drr = 0b00000001;
	adcon1 = 0b00101000;
	cap_mode=0;
}

void status_change(void)
{
		if(status < 0x10)//MAIN MENU
		{
			if((sw_data & SW_LEFT) != 0)
			{
			}else if((sw_data & SW_UP) != 0)
			{
				if(status != MENU_CHG)
				{
					status --;
				}
			}else if((sw_data & SW_DOWN) != 0)
			{
				if(status != MENU_CFG)
				{
					status ++;
				}
			}else if((sw_data & SW_RIGHT) != 0)
			{
				if(status != MENU_CFG)
				{
					status = status + 0x10;
					data_num = 0;
				}else{
					status = MENU_CFG_BAT;
				}
			}
		}else if(status == MENU_CHG_LOAD)//charge load menu
		{
			if((sw_data & SW_LEFT) != 0)
			{
				status = MENU_CHG;
			}else if((sw_data & SW_UP) != 0)
			{
				if(data_num != 0)
				{
					data_num --;
				}
			}else if((sw_data & SW_DOWN) != 0)
			{
				if(data_num != 15)
				{
					data_num ++;
				}
			}else if((sw_data & SW_RIGHT) != 0)
			{
				read_data(data_setting, BANK_A+data_num*16,16);
				data_check(data_setting);
				status = MENU_CHG_START;
			}
		}else if(status == MENU_DIS_LOAD)//discharge load menu
		{
			if((sw_data & SW_LEFT) != 0)
			{
				status = MENU_DIS;
			}else if((sw_data & SW_UP) != 0)
			{
				if(data_num != 0)
				{
					data_num --;
				}
			}else if((sw_data & SW_DOWN) != 0)
			{
				if(data_num != 15)
				{
					data_num ++;
				}
			}else if((sw_data & SW_RIGHT) != 0)
			{
				read_data(data_setting, BANK_A+data_num*16+512,16);
				data_check(data_setting);
				status = MENU_DIS_START;
			}
		}else if(status == MENU_SEQ_LOAD)//sequence load menu
		{
			if((sw_data & SW_LEFT) != 0)
			{
				status = MENU_SEQ;
			}else if((sw_data & SW_UP) != 0)
			{
				if(data_num != 0)
				{
					data_num --;
				}
			}else if((sw_data & SW_DOWN) != 0)
			{
				if(data_num != 3)
				{
					data_num ++;
				}
			}else if((sw_data & SW_RIGHT) != 0)
			{
				pc = 0;
				read_data(data_seq, BANK_B+data_num*256,256);
				status = MENU_SEQ_START;
			}

		}else if(status <0x30)//charge MENU
		{
			if((sw_data & SW_LEFT) != 0)
			{
				status = MENU_CHG_LOAD;
				edit_mode_off();
			}else if((sw_data & SW_UP) != 0)
			{
				if((status != MENU_CHG_START) && (setting_mode == NOT_EDIT_MODE))
				{
					status --;
				}
			}else if((sw_data & SW_DOWN) != 0)
			{
				if((status != MENU_CHG_SAVE) && (setting_mode == NOT_EDIT_MODE))
				{
					status ++;
				}
			}else if((sw_data & SW_RIGHT) != 0)
			{
//				status = MENU_CHG;

			}
		}else if(status <0x40)//discharge MENU
		{
			if((sw_data & SW_LEFT) != 0)
			{
				status = MENU_DIS_LOAD;
				edit_mode_off();
			}else if((sw_data & SW_UP) != 0)
			{
				if((status != MENU_DIS_START) && (setting_mode == NOT_EDIT_MODE))
				{
					status --;
				}
			}else if((sw_data & SW_DOWN) != 0)
			{
				if((status != MENU_DIS_SAVE) && (setting_mode == NOT_EDIT_MODE))
				{
					status ++;
				}
			}else if((sw_data & SW_RIGHT) != 0)
			{
//				status = MENU_CHG;
			}
		}else if(status <0x50)//seq MENU
		{
			if((sw_data & SW_LEFT) != 0)
			{
				status = MENU_SEQ_LOAD;
				edit_mode_off();
			}else if((sw_data & SW_UP) != 0)
			{
				if((status == MENU_SEQ_SETTING) && (pc > 0) && (setting_mode == NOT_EDIT_MODE))
				{
					pc--;
				}else if((status != MENU_SEQ_START) && (pc == 0) && (setting_mode == NOT_EDIT_MODE))
				{
					status--;
				}else if(status == MENU_SEQ_START)
				{
					status = MENU_SEQ_SETTING;
					pc = 255;
				}
			}else if((sw_data & SW_DOWN) != 0)
			{
				if((status != MENU_SEQ_SETTING) && (setting_mode == NOT_EDIT_MODE))
				{
					status ++;
					pc = 0;
				}else if((status == MENU_SEQ_SETTING) && (pc < 255) && (setting_mode == NOT_EDIT_MODE))
				{
					pc++;
				}else if((status == MENU_SEQ_SETTING) && (pc == 255) && (setting_mode == NOT_EDIT_MODE))
				{
					status = MENU_SEQ_START;
					pc = 0;
				}
			}else if((sw_data & SW_RIGHT) != 0)
			{
//				status = MENU_CHG;
			}

		}else if(status <0x60)//config MENU
		{
			if((sw_data & SW_LEFT) != 0)
			{
				status = MENU_CFG;
				edit_mode_off();
			}else if((sw_data & SW_UP) != 0)
			{
				if((status != MENU_CFG_BAT) && (setting_mode == NOT_EDIT_MODE))
				{
					status --;
				}
			}else if((sw_data & SW_DOWN) != 0)
			{
				if((status != MENU_CFG_RST) && (setting_mode == NOT_EDIT_MODE))
				{
					status ++;
				}
			}else if((sw_data & SW_RIGHT) != 0)
			{
//				status = MENU_CHG;
			}
		}
}
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

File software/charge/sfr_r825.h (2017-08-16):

/***********************************************************************/
/*                                                                     */
/*                                                                     */
/*                                                                     */
/*  DESCRIPTION :define the sfr register. (for C language)             */
/*                                                                     */
/*                                                                     */
/*  This file is generated by Renesas Project Generator.               */
/*                                                                     */
/***********************************************************************/
/***********************************************************************
*
* Device       : R8C/24,25
*
* File Name    : sfr_r825.h
*
* Abstract     : Define the sfr register.
*
* History      : 1.40 (06-06-08)
*              : 1.30 (05-11-30)
*              : 1.20 (05-10-04)
*              : 1.10 (05-08-08)
*              : 1.00 (05-08-01)
*
* NOTE         : THIS IS A TYPICAL EXAMPLE.
*
* Copyright (C) 2005 (2006) Renesas Electronics Corporation.
* and Renesas Solutions Corp.
*
************************************************************************/

/********************************************************
*  declare SFR addresses                                *
********************************************************/

#pragma	ADDRESS		pm0_addr		0004H	/* Processor mode register 0 */

#pragma	ADDRESS		pm1_addr		0005H	/* Processor mode register 1 */

#pragma	ADDRESS		cm0_addr		0006H	/* System clock control register 0 */

#pragma	ADDRESS		cm1_addr		0007H	/* System clock control register 1 */

#pragma	ADDRESS		prcr_addr		000AH	/* Protect register */

#pragma	ADDRESS		ocd_addr		000CH	/* Oscillation stop detect register */

#pragma	ADDRESS		wdtr_addr		000DH	/* Watchdog timer reset register */

#pragma	ADDRESS		wdts_addr		000EH	/* Watchdog timer start register */

#pragma	ADDRESS		wdc_addr		000FH	/* Watchdog timer control register */

#pragma	ADDRESS		rmad0_addr		0010H	/* Address match interrupt register0 */

#pragma	ADDRESS		aier_addr		0013H	/* Address match interrupt enable register */

#pragma	ADDRESS		rmad1_addr		0014H	/* Address match interrupt register1 */

#pragma	ADDRESS		cspr_addr		001CH	/* Count source protect mode register */

#pragma	ADDRESS		fra0_addr		0023H	/* High-speed on-chip oscillator contorl register 0 */

#pragma	ADDRESS		fra1_addr		0024H	/* High-speed on-chip oscillator contorl register 1 */

#pragma	ADDRESS		fra2_addr		0025H	/* High-speed on-chip oscillator contorl register 2 */

#pragma	ADDRESS		cpsrf_addr		0028H	/* Clock prescaler reset flag */

#pragma	ADDRESS		fra4_addr		0029H	/* High-speed on-chip oscillator contorl register 4 */

#pragma	ADDRESS		fra6_addr		002BH	/* High-speed on-chip oscillator contorl register 6 */

#pragma	ADDRESS		vca1_addr		0031H	/* Voltage detection register 1 */

#pragma	ADDRESS		vca2_addr		0032H	/* Voltage detection register 2 */

#pragma	ADDRESS		vw1c_addr		0036H	/* Voltage monitor 1 circuit control register */

#pragma	ADDRESS		vw2c_addr		0037H	/* Voltage monitor 2 circuit control register */

#pragma	ADDRESS		vw0c_addr		0038H	/* Voltage monitor 0 circuit control register */

#pragma	ADDRESS		trd0ic_addr		0048H	/* Timer RD0 interrupt control register */

#pragma	ADDRESS		trd1ic_addr		0049H	/* Timer RD1 interrupt control register */

#pragma	ADDRESS		treic_addr		004AH	/* Timer RE interrupt control register */

#pragma	ADDRESS		kupic_addr		004DH	/* Key input interrupt control register */

#pragma	ADDRESS		adic_addr		004EH	/* A-D conversion interrupt control register */

#pragma	ADDRESS		ssuic_addr		004FH	/* SSU interrupt control register */

#pragma	ADDRESS		iicic_addr		004FH	/* IIC interrupt control register */

#pragma	ADDRESS		s0tic_addr		0051H	/* UART0 transmit interrupt control register */

#pragma	ADDRESS		s0ric_addr		0052H	/* UART0 receive interrupt control register */

#pragma	ADDRESS		s1tic_addr		0053H	/* UART1 transmit interrupt control register */

#pragma	ADDRESS		s1ric_addr		0054H	/* UART1 receive interrupt control register */

#pragma	ADDRESS		int2ic_addr		0055H	/* INT2 interrupt control register */

#pragma	ADDRESS		traic_addr		0056H	/* Timer RA interrupt control register */

#pragma	ADDRESS		trbic_addr		0058H	/* Timer RB interrupt control register */

#pragma	ADDRESS		int1ic_addr		0059H	/* INT1 interrupt control register */

#pragma	ADDRESS		int3ic_addr		005AH	/* INT3 interrupt control register */

#pragma	ADDRESS		int0ic_addr		005DH	/* INT0 interrupt control register */

#pragma	ADDRESS		u0mr_addr		00A0H	/* UART0 transmit/receive mode register */

#pragma	ADDRESS		u0brg_addr		00A1H	/* UART0 bit rate register */

#pragma	ADDRESS		u0tb_addr		00A2H	/* UART0 transmit buffer register */

#pragma	ADDRESS		u0c0_addr		00A4H	/* UART0 transmit/receive control register 0 */

#pragma	ADDRESS		u0c1_addr		00A5H	/* UART0 transmit/receive control register 1 */

#pragma	ADDRESS		u0rb_addr		00A6H	/* UART0 receive buffer register */

#pragma	ADDRESS		u1mr_addr		00A8H	/* UART1 transmit/receive mode register */

#pragma	ADDRESS		u1brg_addr		00A9H	/* UART1 bit rate register */

#pragma	ADDRESS		u1tb_addr		00AAH	/* UART1 transmit buffer register */

#pragma	ADDRESS		u1c0_addr		00ACH	/* UART1 transmit/receive control register 0 */

#pragma	ADDRESS		u1c1_addr		00ADH	/* UART1 transmit/receive control register 1 */

#pragma	ADDRESS		u1rb_addr		00AEH	/* UART1 receive buffer register */

#pragma	ADDRESS		sscrh_addr		00B8H	/* SS control register H */

#pragma	ADDRESS		iccr1_addr		00B8H	/* IIC bus control register 1 */

#pragma	ADDRESS		sscrl_addr		00B9H	/* SS control register L */

#pragma	ADDRESS		iccr2_addr		00B9H	/* IIC bus control register 2 */

#pragma	ADDRESS		ssmr_addr		00BAH	/* SS mode register */

#pragma	ADDRESS		icmr_addr		00BAH	/* IIC bus mode register */

#pragma	ADDRESS		sser_addr		00BBH	/* SS enable register */

#pragma	ADDRESS		icier_addr		00BBH	/* IIC bus interrupt enable register */

#pragma	ADDRESS		sssr_addr		00BCH	/* SS status register */

#pragma	ADDRESS		icsr_addr		00BCH	/* IIC bus status register */

#pragma	ADDRESS		ssmr2_addr		00BDH	/* SS mode register 2 */

#pragma	ADDRESS		sar_addr		00BDH	/* Slave address register */

#pragma	ADDRESS		sstdr_addr		00BEH	/* SS transmit data register */

#pragma	ADDRESS		icdrt_addr		00BEH	/* IIC bus transmit data register */

#pragma	ADDRESS		ssrdr_addr		00BFH	/* SS receive data register */

#pragma	ADDRESS		icdrr_addr		00BFH	/* IIC bus receive data register */

#pragma	ADDRESS		ad_addr			00C0H	/* A-D register */

#pragma	ADDRESS		adcon2_addr		00D4H	/* A-D control register 2 */

#pragma	ADDRESS		adcon0_addr		00D6H	/* A-D control register 0 */

#pragma	ADDRESS		adcon1_addr		00D7H	/* A-D control register 1 */

#pragma	ADDRESS		p0_addr			00E0H	/* Port P0 register */

#pragma	ADDRESS		p1_addr			00E1H	/* Port P1 register */
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

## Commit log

2017-08-16 first hardware commit
    [charge-B.Cu.gbr, charge-B.Mask.gbr, charge-B.SilkS.gbr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]
2017-08-16 some file added
    [setting sheet.ods]
